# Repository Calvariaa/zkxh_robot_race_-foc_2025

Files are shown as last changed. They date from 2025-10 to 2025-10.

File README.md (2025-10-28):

# 光电管循迹FOC版 STM32G431驱动+主控

车模图片
------

## 介绍

	省一方案

	本次开源包含源代码、PCB文件、3D文件。工程花费大半个月是随便挫的，东拼西凑所以显得有些凌乱，如果有想要复刻本车的记得把foc部分的PC3引脚改为PA4（画错了所以最后飞的线）

## 特殊物料

- WeAct STM32G431核心板
- 4008无刷电机
- 随便型号的光电对管
- ICM42688

## 感谢

- 我自己的另一个开源 https://github.com/Calvariaa/zkxh_20th_photoelectric_foc_car_cyt4bb7
- 逐飞科技的打表foc https://gitee.com/seekfree/CYT2BL3_Brushless_Driver_Project
- 我的女朋友^^

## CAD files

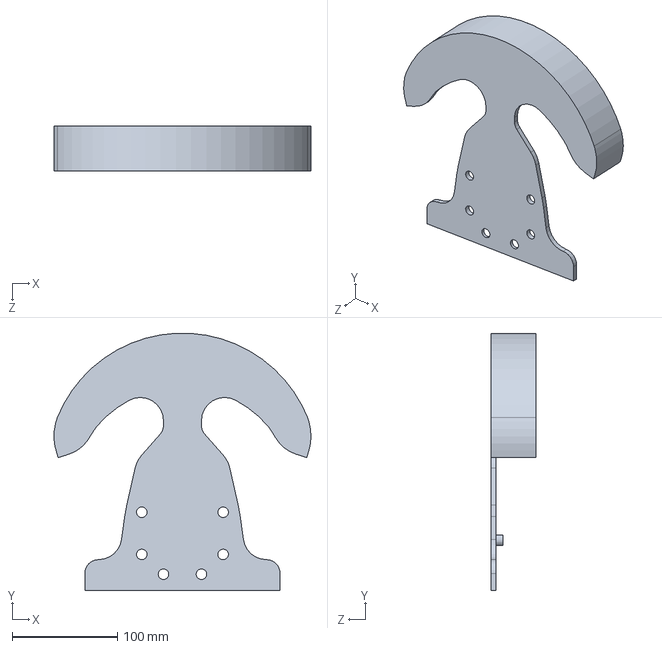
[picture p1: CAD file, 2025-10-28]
3d/包装壳(前).SLDPRT
243.7 x 244.1 x 43.0 mm

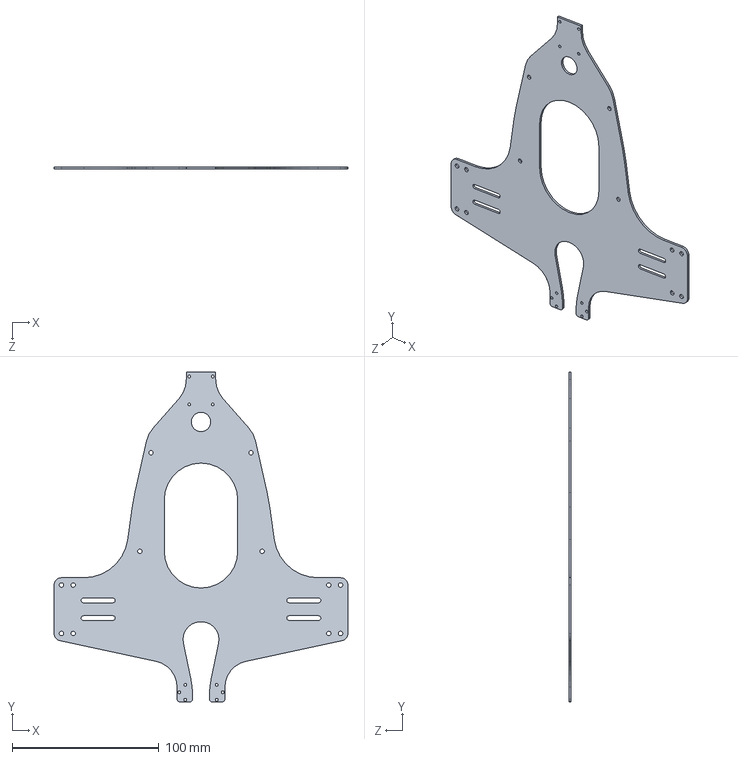
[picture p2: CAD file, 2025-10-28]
3d/底盘.SLDPRT
200.0 x 224.6 x 1.60 mm

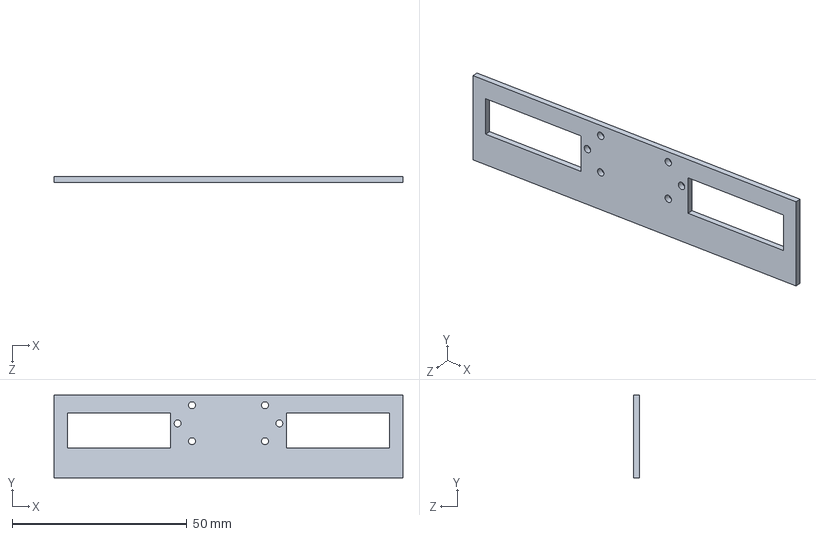
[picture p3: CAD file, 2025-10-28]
3d/后瞻.SLDPRT
99.9 x 23.7 x 1.60 mm

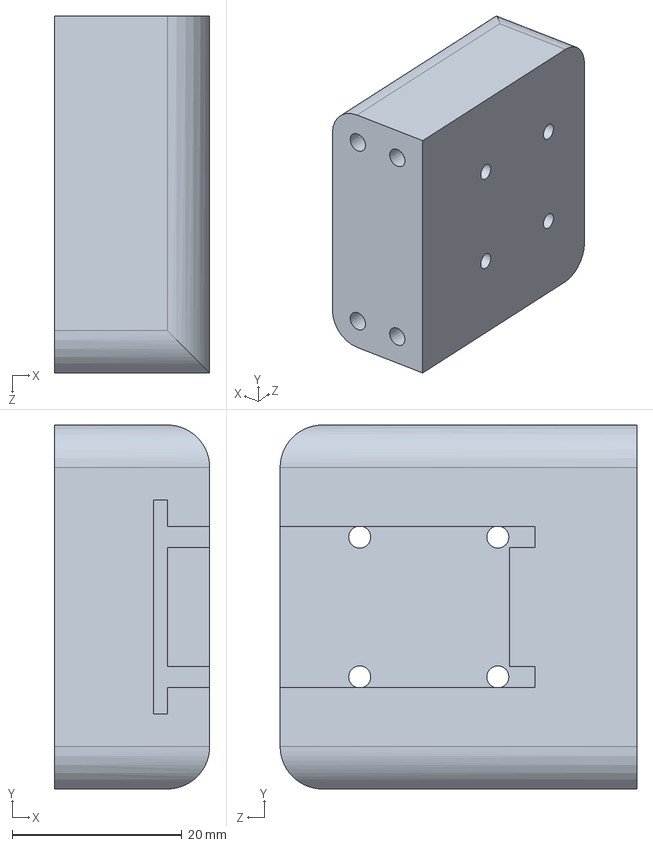
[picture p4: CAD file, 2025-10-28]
3d/后桥.SLDPRT
18.3 x 42.8 x 42.0 mm

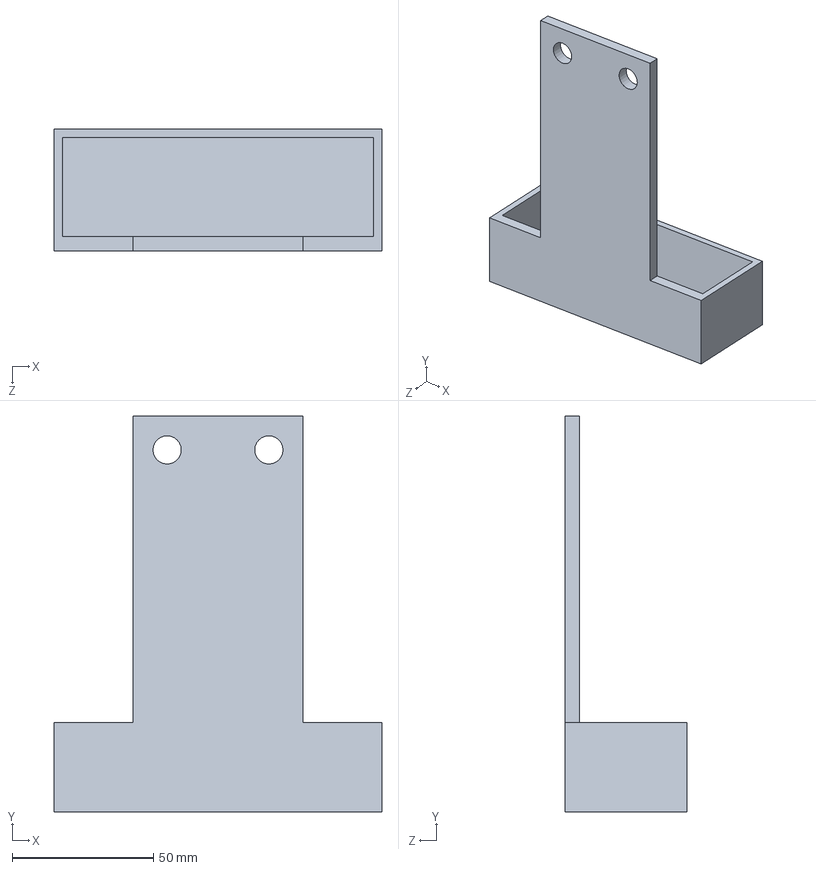
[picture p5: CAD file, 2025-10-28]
3d/包装壳(后).SLDPRT
116.0 x 140.1 x 43.0 mm

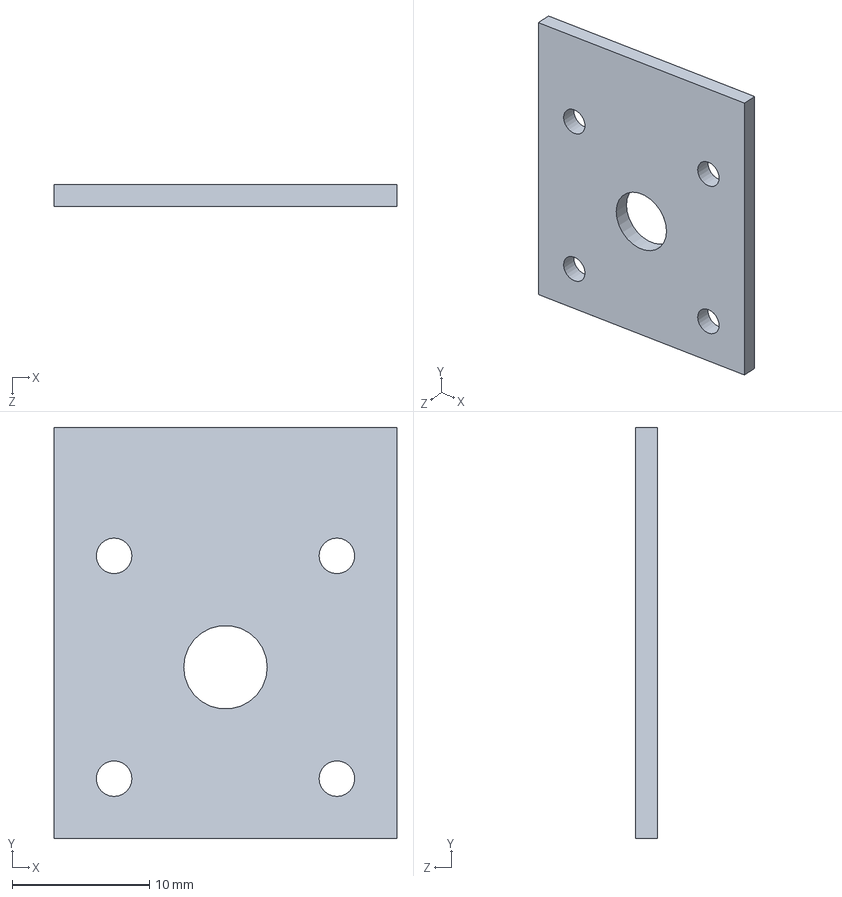
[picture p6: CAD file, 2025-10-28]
3d/4008电机磁铁固定件.SLDPRT
25.0 x 30.0 x 1.60 mm

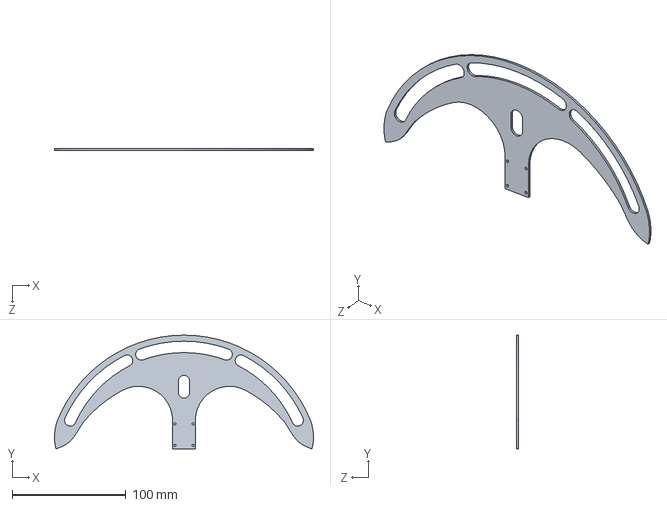
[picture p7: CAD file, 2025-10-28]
3d/前瞻.SLDPRT
227.7 x 100.0 x 1.60 mm

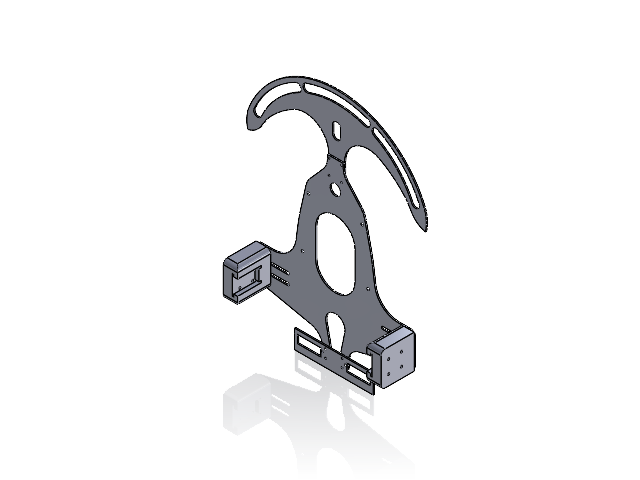
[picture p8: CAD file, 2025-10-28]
3d/车体装配体.SLDASM
底盘
机器人前瞻
后瞻
后桥2 x 2

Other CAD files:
3d/零件1.SLDPRT
3d/前瞻(嘉立创).SLDPRT
3d/底盘.DXF

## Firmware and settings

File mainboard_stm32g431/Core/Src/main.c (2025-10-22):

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
/* Includes ------------------------------------------------------------------*/
#include "main.h"
#include "dma.h"
#include "i2c.h"
#include "tim.h"
#include "usb_device.h"
#include "gpio.h"

/* USER CODE BEGIN Includes */
#include "usbd_cdc_if.h"
#include "ssd1306.h"
#include "icm42688.h"
#include "interface.h"
/* USER CODE END Includes */


void SystemClock_Config(void);
/* USER CODE BEGIN 0 */

extern uint64_t total_time_10ms;
/* USER CODE END 0 */

/**
  * @brief  The application entry point.
  * @retval int
  */
int main(void)
{

  /* MCU Configuration--------------------------------------------------------*/

  /* Reset of all peripherals, Initializes the Flash interface and the Systick. */
  HAL_Init();

  /* Configure the system clock */
  SystemClock_Config();

  /* Initialize all configured peripherals */
  MX_GPIO_Init();
  MX_DMA_Init();
  MX_USB_Device_Init();
  MX_I2C1_Init();
  MX_TIM2_Init();
  MX_I2C2_Init();
  MX_TIM6_Init();
  MX_TIM4_Init();
  MX_TIM15_Init();
  /* USER CODE BEGIN 2 */
  ssd1306_Init();
  ssd1306_FlipScreenVertically();
  ssd1306_SetColor(White);

  HAL_Delay(100);
  // 初始化ICM42688
  ICM42688_Init(&hi2c2);

  HAL_TIM_Encoder_Start(&htim2, TIM_CHANNEL_ALL);

  HAL_I2C_Mem_Read_DMA(&hi2c2, ICM42688_ADDRESS << 1, GYRO_DATA_X1, 1, dma_gyro_data, 6);

  HAL_TIM_Base_Start_IT(&htim6);

  HAL_TIM_PWM_Start(&htim4,TIM_CHANNEL_1);
  HAL_TIM_PWM_Start(&htim4,TIM_CHANNEL_2);

  HAL_TIM_IC_Start_IT(&htim15, TIM_CHANNEL_1);
  HAL_TIM_IC_Start_IT(&htim15, TIM_CHANNEL_2);
  /* USER CODE END 2 */

  /* Infinite loop */
  /* USER CODE BEGIN WHILE */
  __HAL_TIM_SET_COMPARE(&htim15, TIM_CHANNEL_2, TX_COUNT_PERIOD / 2);  // L_TX
  __HAL_TIM_SET_COMPARE(&htim4, TIM_CHANNEL_2, TX_COUNT_PERIOD / 2);  // R_TX
  while (1) {
    /* USER CODE END WHILE */

    /* USER CODE BEGIN 3 */

    interface_main();
  }
  /* USER CODE END 3 */
}

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
/* USER CODE BEGIN 4 */


int _write(const int file, char *ptr, const int len) {
  CDC_Transmit_FS((uint8_t *)ptr, len);
  (void)file;
  // static uint8_t rc = USBD_OK;
  //
  // do {
  //   rc = CDC_Transmit_FS(ptr, len);
  // } while (USBD_BUSY == rc);
  //
  // if (USBD_FAIL == rc) {
  //   /// NOTE: Should never reach here.
  //   return 0;
  // }
  return len;
}

/* USER CODE END 4 */
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


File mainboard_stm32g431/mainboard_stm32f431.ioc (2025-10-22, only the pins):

Mcu.UserName=STM32G431CBUx
PA0.Signal=S_TIM2_CH1
PA1.Signal=S_TIM2_CH2
PA10.GPIO_Label=LED_F12
PA10.Signal=GPIO_Input
PA11.Signal=USB_DM
PA12.Signal=USB_DP
PA15.Signal=I2C1_SCL
PA2.GPIO_Label=L_R
PA2.Signal=S_TIM15_CH1
PA3.GPIO_Label=L_L
PA3.Signal=S_TIM15_CH2
PA4.GPIO_Label=LED_F3
PA4.Signal=GPIO_Input
PA5.GPIO_Label=LED_F5
PA5.Signal=GPIO_Input
PA6.GPIO_Label=LED_F4
PA6.Signal=GPIO_Input
PA7.GPIO_Label=LED_F6
PA7.Signal=GPIO_Input
PA8.Signal=I2C2_SDA
PA9.Signal=I2C2_SCL
PB0.GPIO_Label=LED_B0
PB0.Signal=GPIO_Input
PB1.GPIO_Label=LED_F8
PB1.Signal=GPIO_Input
PB10.GPIO_Label=LED_B3
PB10.Signal=GPIO_Input
PB11.GPIO_Label=LED_B2
PB11.Signal=GPIO_Input
PB12.GPIO_Label=LED_B4
PB12.Signal=GPIO_Input
PB13.GPIO_Label=LED_B5
PB13.Signal=GPIO_Input
PB14.GPIO_Label=LED_F10
PB14.Signal=GPIO_Input
PB15.GPIO_Label=LED_F9
PB15.Signal=GPIO_Input
PB2.GPIO_Label=LED_B1
PB2.Signal=GPIO_Input
PB3.GPIO_Label=LED_F14
PB3.Signal=GPIO_Input
PB4.GPIO_Label=LED_F16
PB4.Signal=GPIO_Input
PB5.GPIO_Label=LED_F17
PB5.Signal=GPIO_Input
PB6.GPIO_Label=R_R
PB6.Signal=S_TIM4_CH1
PB7.GPIO_Label=R_L
PB7.Signal=S_TIM4_CH2
PB9.Signal=I2C1_SDA
PC10.GPIO_Label=LED_F13
PC10.Signal=GPIO_Input
PC11.GPIO_Label=LED_F15
PC11.Signal=GPIO_Input
PC13.GPIO_Label=LED_F0
PC13.Signal=GPIO_Input
PC14-OSC32_IN.GPIO_Label=LED_F1
PC14-OSC32_IN.Signal=GPIO_Input
PC15-OSC32_OUT.GPIO_Label=LED_F2
PC15-OSC32_OUT.Signal=GPIO_Input
PC4.GPIO_Label=LED_F7
PC4.Signal=GPIO_Input
PC6.GPIO_Label=LED_F11
PC6.Signal=GPIO_Input
PF0-OSC_IN.Signal=RCC_OSC_IN
PF1-OSC_OUT.Signal=RCC_OSC_OUT
PG10-NRST.GPIO_Label=PRESS
PG10-NRST.Signal=GPIO_Input

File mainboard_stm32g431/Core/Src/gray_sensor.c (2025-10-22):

#include "gray_sensor.h"

#include "control.h"
#include "gpio.h"

bool gray_forward_value[MAX_FRONT_LED] = {0};
bool gray_backward_value[MAX_BACK_LED] = {0};

void read_gray_sensor(void) {
  gray_forward_value[0] = HAL_GPIO_ReadPin(LED_F0_GPIO_Port, LED_F0_Pin);
  gray_forward_value[1] = HAL_GPIO_ReadPin(LED_F1_GPIO_Port, LED_F1_Pin);
  gray_forward_value[2] = HAL_GPIO_ReadPin(LED_F1_GPIO_Port, LED_F2_Pin);
  gray_forward_value[3] = HAL_GPIO_ReadPin(LED_F3_GPIO_Port, LED_F3_Pin);
  gray_forward_value[4] = HAL_GPIO_ReadPin(LED_F4_GPIO_Port, LED_F4_Pin);
  gray_forward_value[5] = HAL_GPIO_ReadPin(LED_F5_GPIO_Port, LED_F5_Pin);
  gray_forward_value[6] = HAL_GPIO_ReadPin(LED_F6_GPIO_Port, LED_F6_Pin);
  gray_forward_value[7] = HAL_GPIO_ReadPin(LED_F7_GPIO_Port, LED_F7_Pin);
  gray_forward_value[8] = HAL_GPIO_ReadPin(LED_F8_GPIO_Port, LED_F8_Pin);
  gray_forward_value[9] = HAL_GPIO_ReadPin(LED_F9_GPIO_Port, LED_F9_Pin);
  gray_forward_value[10] = HAL_GPIO_ReadPin(LED_F10_GPIO_Port, LED_F10_Pin);
  gray_forward_value[11] = HAL_GPIO_ReadPin(LED_F11_GPIO_Port, LED_F11_Pin);
  gray_forward_value[12] = HAL_GPIO_ReadPin(LED_F12_GPIO_Port, LED_F12_Pin);
  gray_forward_value[13] = HAL_GPIO_ReadPin(LED_F13_GPIO_Port, LED_F13_Pin);
  gray_forward_value[14] = HAL_GPIO_ReadPin(LED_F14_GPIO_Port, LED_F14_Pin);
  gray_forward_value[15] = HAL_GPIO_ReadPin(LED_F15_GPIO_Port, LED_F15_Pin);
  gray_forward_value[16] = HAL_GPIO_ReadPin(LED_F16_GPIO_Port, LED_F16_Pin);
  gray_forward_value[17] = HAL_GPIO_ReadPin(LED_F17_GPIO_Port, LED_F17_Pin);

  gray_backward_value[0] = HAL_GPIO_ReadPin(LED_B0_GPIO_Port, LED_B0_Pin);
  gray_backward_value[1] = HAL_GPIO_ReadPin(LED_B1_GPIO_Port, LED_B1_Pin);
  gray_backward_value[2] = HAL_GPIO_ReadPin(LED_B2_GPIO_Port, LED_B2_Pin);
  gray_backward_value[3] = HAL_GPIO_ReadPin(LED_B3_GPIO_Port, LED_B3_Pin);
  gray_backward_value[4] = HAL_GPIO_ReadPin(LED_B4_GPIO_Port, LED_B4_Pin);
  gray_backward_value[5] = HAL_GPIO_ReadPin(LED_B5_GPIO_Port, LED_B5_Pin);
}

void outline_check(void) {
  bool outline = true;
  for (uint8_t i = 0; i < MAX_FRONT_LED; i++) {
    if (gray_forward_value[i]) {
      outline = false;
      return;
    }
  }
  control_state = STOP;
}

int8_t calc_left_right_error(void) {
  uint8_t left = 0;
  uint8_t right = 18;
  for (uint8_t i = 0; i < MAX_FRONT_LED; i++) {
    if (gray_forward_value[i]) {
      left = i;
    }
  }
  for (uint8_t i = MAX_FRONT_LED; i > 0; i--) {
    if (gray_forward_value[i - 1]) {
      right = i;
    }
  }
  return left + right - MAX_FRONT_LED;
}

int8_t calc_left_right_error_enhanced(void) {
  uint8_t left_start = 0;
  uint8_t left_end = 18;
  uint8_t right_start = 18;
  uint8_t right_end = 0;

  // 寻找左边第一个白色点
  for (uint8_t i = 0; i < MAX_FRONT_LED; i++) {
    if (gray_forward_value[i]) {
      left_start = i;
      break;
    }
  }

  // 寻找右边第一个白色点
  for (uint8_t i = MAX_FRONT_LED; i > 0; i--) {
    if (gray_forward_value[i - 1]) {
      right_start = i - 1;
      break;
    }
  }

  // 如果左右都没有检测到白线，返回0（保持直行或特殊处理）
  if (left_start == 0 && !gray_forward_value[0] &&
      right_start == 18 && !gray_forward_value[17]) {
    return 0;
      }

  // 从左边第一个白色点继续向右寻找白色点结束的位置
  for (uint8_t i = left_start; i < MAX_FRONT_LED; i++) {
    if (!gray_forward_value[i]) {
      left_end = i;
      break;
    }
    // // 如果一直到最右边都是白色，则结束位置为最右边
    // if (i == MAX_FRONT_LED - 1) {
    //   left_end = i;
    // }
  }

  // 从右边第一个白色点继续向左寻找白色点结束的位置
  for (uint8_t i = right_start; i > 0; i--) {
    if (!gray_forward_value[i]) {
      right_end = i;
      break;
    }
    // // 如果一直到最左边都是白色，则结束位置为最左边
    // if (i == 0) {
    //   right_end = i;
    // }
  }

  // 检查左边第一个白色点到右边第一个白色点的范围内是否有白色点
  bool has_white_points = false;
  for (uint8_t i = left_end; i <= right_end; i++) {
    if (gray_forward_value[i]) {
      has_white_points = true;
      break;
    }
  }

  if (has_white_points || left_end > right_end) {
    // 正常循迹：使用左右第一个白色点计算中值
    return left_start + right_start - MAX_FRONT_LED + 1;
  }

    // 特殊处理：使用最右边第一个白色点和白色点结束位置计算中值
    return right_end + right_start - MAX_FRONT_LED + 2;
}

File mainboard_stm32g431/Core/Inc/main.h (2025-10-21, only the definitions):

#define ISR_PRESCALER 170-1
#define ISR_COUNT_PERIOD (TIM_CLK_MHz*1000000/ISR_FREQUENCY/(ISR_PRESCALER + 1)-1)
#define ISR_FREQUENCY 500
#define TIM_CLK_MHz 170
#define RX_PRESCALER 7
#define RX_COUNT_PERIOD 65535
#define TX_FREQUENCY 500
#define TX_PRESCALER 170-1
#define TX_COUNT_PERIOD (TIM_CLK_MHz*1000000/TX_FREQUENCY/(TX_PRESCALER + 1)-1)
#define LED_F0_Pin GPIO_PIN_13
#define LED_F0_GPIO_Port GPIOC
#define LED_F1_Pin GPIO_PIN_14
#define LED_F1_GPIO_Port GPIOC
#define LED_F2_Pin GPIO_PIN_15
#define LED_F2_GPIO_Port GPIOC
#define PRESS_Pin GPIO_PIN_10
#define PRESS_GPIO_Port GPIOG
#define L_R_Pin GPIO_PIN_2
#define L_R_GPIO_Port GPIOA
#define L_L_Pin GPIO_PIN_3
#define L_L_GPIO_Port GPIOA
#define LED_F3_Pin GPIO_PIN_4
#define LED_F3_GPIO_Port GPIOA
#define LED_F5_Pin GPIO_PIN_5
#define LED_F5_GPIO_Port GPIOA
#define LED_F4_Pin GPIO_PIN_6
#define LED_F4_GPIO_Port GPIOA
#define LED_F6_Pin GPIO_PIN_7
#define LED_F6_GPIO_Port GPIOA
#define LED_F7_Pin GPIO_PIN_4
#define LED_F7_GPIO_Port GPIOC
#define LED_B0_Pin GPIO_PIN_0
#define LED_B0_GPIO_Port GPIOB
#define LED_F8_Pin GPIO_PIN_1
#define LED_F8_GPIO_Port GPIOB
#define LED_B1_Pin GPIO_PIN_2
#define LED_B1_GPIO_Port GPIOB
#define LED_B3_Pin GPIO_PIN_10
#define LED_B3_GPIO_Port GPIOB
#define LED_B2_Pin GPIO_PIN_11
#define LED_B2_GPIO_Port GPIOB
#define LED_B4_Pin GPIO_PIN_12
#define LED_B4_GPIO_Port GPIOB
#define LED_B5_Pin GPIO_PIN_13
#define LED_B5_GPIO_Port GPIOB
#define LED_F10_Pin GPIO_PIN_14
#define LED_F10_GPIO_Port GPIOB
#define LED_F9_Pin GPIO_PIN_15
#define LED_F9_GPIO_Port GPIOB
#define LED_F11_Pin GPIO_PIN_6
#define LED_F11_GPIO_Port GPIOC
#define LED_F12_Pin GPIO_PIN_10
#define LED_F12_GPIO_Port GPIOA
#define LED_F13_Pin GPIO_PIN_10
#define LED_F13_GPIO_Port GPIOC
#define LED_F15_Pin GPIO_PIN_11
#define LED_F15_GPIO_Port GPIOC
#define LED_F14_Pin GPIO_PIN_3
#define LED_F14_GPIO_Port GPIOB
#define LED_F16_Pin GPIO_PIN_4
#define LED_F16_GPIO_Port GPIOB
#define LED_F17_Pin GPIO_PIN_5
#define LED_F17_GPIO_Port GPIOB
#define R_R_Pin GPIO_PIN_6
#define R_R_GPIO_Port GPIOB
#define R_L_Pin GPIO_PIN_7
#define R_L_GPIO_Port GPIOB

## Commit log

2025-09-27 update pcb
2025-09-30 update nrst setting
    [stlink.cfg]
2025-09-30 update pcb and cubemx
2025-10-04 更新主板
2025-10-04 更新pcb
2025-10-11 更新屏幕库
2025-10-17 添加菜单
2025-10-17 完善foc
2025-10-18 add uart and fifo
2025-10-18 完成uq控制，准备上串口
2025-10-19 change uart to pwm
2025-10-20 封装pwm捕获
2025-10-21 finish connect on boards
2025-10-22 改陀螺仪i2c bug
2025-10-28 add 3d file
    add 3d file
    [4008电机磁铁固定件.SLDPRT, 前瞻(嘉立创).SLDPRT, 前瞻.SLDPRT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]
2025-10-28 fix folder name
    [stlink.cfg]
2025-11-05 Add 牛眼轮 SP-8 to the hardware list

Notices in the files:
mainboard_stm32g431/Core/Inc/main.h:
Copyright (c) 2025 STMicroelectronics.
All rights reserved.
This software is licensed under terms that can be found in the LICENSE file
